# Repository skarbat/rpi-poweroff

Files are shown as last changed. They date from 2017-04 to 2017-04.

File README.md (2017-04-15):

# rpi-poweroff

The RaspberyPI does not have a power button to turn it off from hardware.

This is a simple microcontroller based solution that resolves this.
It enables to cut power off the Raspberry after a clean shutdown.

A gpio is set HIGH while the PI is running, and it goes LOW after a software power off.
It is controlled by the `gpio-poweroff` overlay from the RaspberryPI firmware.

I used a Adafruit feather board, but many more variations should do the same work.

## Software setup

Enable the overlay in config.txt with `dtoverlay=gpio-poweroff,gpiopin=16,active_low=y`.
An alternative is to load it at run time with `sudo dtoverlay gpio-poweroff gpiopin=16 active_low=y`.

The bash script `raspberry/rpi-poweroff` can be enabled through `/etc/rc.local` to automate it.

## Wiring

There are 3 connections needed. A powerup transistor, a detection pin, and the poweroff pin.

 * Connect BCM16 from the RaspberryPI to Pin 11 on the Feather - will go LOW when the PI powers off
 * Connect GND from the RaspberryPI to GND on the Feather
 * Connect a 4.5 KOhm resistor between BCM16 to 3.3v - guarantees a HIGH when power is applied.
 * Connect Pin 5 on the feather to a transistor base, then RPi 5V and GND to collector / emitter - use a resistor on the base
 * Connect Pin 13 from the feather to BCM17 on the Raspberry - this is a probe pin set to HIGH when controller available

See more details in the `schematics` folder.

## Running

Connect the Feather to your computer through the USB and open the Serial Monitor from the Arduino IDE.
It will turn on the RaspberryPI after 3 seconds.

From the RPi, insert the overlay as explained above, then do a `sudo poweroff`. The feather will detect
the power off and will cut power to the board through the transistor.

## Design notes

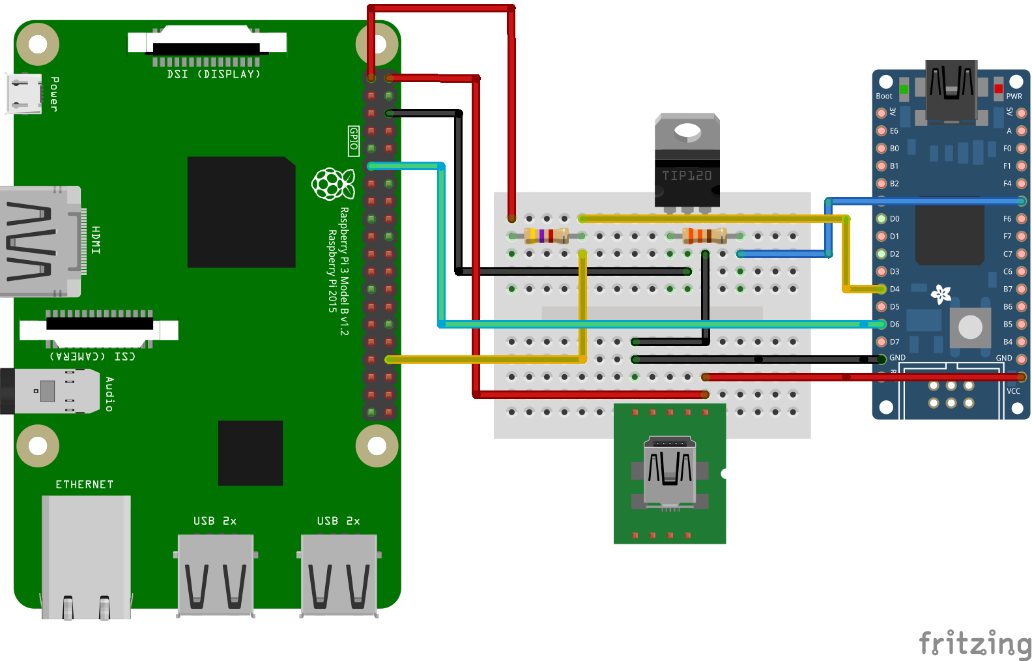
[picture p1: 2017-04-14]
schematics/rpi-poweroff.png

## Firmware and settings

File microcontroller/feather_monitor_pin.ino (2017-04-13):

/*
 * for the adafruit feather 32u4
 *
 * Monitor when a pin goes high, output state changes to the serial console
 * 
 */

// The RPi sets it LOW to request a power off
int poweroff_pin=11;

// Is set HIGH to let the RPi detect the battery
int detection_pin=13;

// Connected to a transistor, turns the RPi ON and OFF
int rpi_power_pin=5;

// Used to monitor poweroff_pin changes
int poweroff_status=0;


int get_poweroff_status()
{
   return digitalRead(poweroff_pin);
}


void setup() {

  // initial delay to allow serial console to get ready
  Serial.begin(9600);
  delay(3000);

  // Setup pin directions and statuses
  pinMode(poweroff_pin, INPUT);
  poweroff_status=get_poweroff_status();

  delay(20);

  pinMode(detection_pin, OUTPUT);
  digitalWrite(detection_pin, HIGH);

  delay(20);

  // when the Feather wakes up, we power on the raspberry pi
  pinMode(rpi_power_pin, OUTPUT);
  digitalWrite(rpi_power_pin, HIGH);

  delay(20);

  Serial.print("poweroff_pin is ");
  Serial.println(poweroff_status);
  Serial.println("monitoring...");
}


void loop() {

  if (poweroff_status != get_poweroff_status()) {

    poweroff_status = !poweroff_status;
    Serial.print("uptime: ");
    Serial.print(millis());
  
    Serial.print(" monitor pin has changed to: ");
    Serial.println(poweroff_status);

    // if the raspberry pi signals a LOW, power it off - gpio-poweroff overlay
    if (poweroff_status == 0) {
      Serial.println("powering off the raspberry pi");
      delay(1500);
      digitalWrite(rpi_power_pin, LOW);
    }
  }
}

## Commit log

2017-04-13 Added transistor and probe pin
2017-04-14 Adding wiring schematics
    [rpi-poweroff.fzz]
2017-04-15 Adding script to enable power off pin, updated README
